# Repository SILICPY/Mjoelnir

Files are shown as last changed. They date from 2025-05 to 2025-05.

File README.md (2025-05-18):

# 🔨 Mjölnir
Eine dekorative Leuchte angelehnt an Marvels Interpretation des Hammers Thors

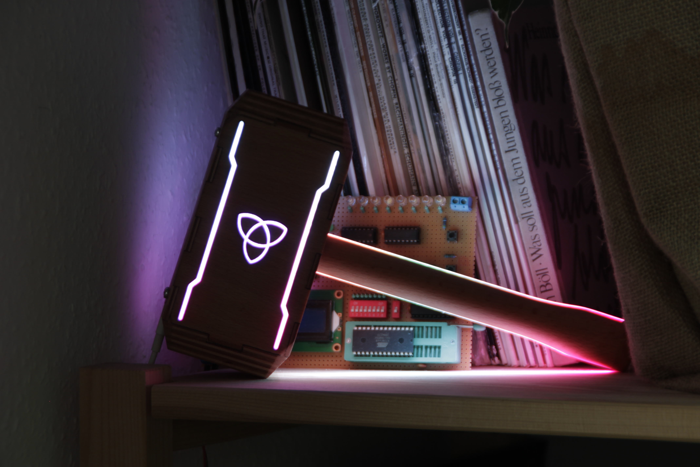
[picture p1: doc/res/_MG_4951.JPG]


## 📖 Dokumentation
<!-- - [Mjölnir dokumentation](doc/) -->
- [WLED Dokumentation](https://kno.wled.ge/) - ESP32 LED Firmware
- [LedFX Dokumentation](https://docs.ledfx.app/en/stable/) - Rhythmuserkennungssoftware
- [Reparaturanleitung (WIP)](/doc/repairguide.md)

## 🚀 Erste Schritte
### 🛠️ Systemkonfiguration
- [x] [ESP32](https://amzn.eu/d/4D6PdJC) mit [WLED Firmware](https://github.com/wled/WLED/releases/latest) [flashen](kno.wled.ge/basics/install-binary/)
- [x] [ATtiny85 / Digispark USB](https://amzn.eu/d/9wXMY9x) mit [USB-C Supervisor Firmware flashen](/software/usb_controller/)
- [x] Verbinden mit AP des ESP32
    - Netzwerkname: `WLED-AP`
    - Passwort: `wled1234`
- [x] Navigiere zu http://4.3.2.1/settings/sec
    - [x] Hochladen der [Preset-Konfigurationsdatei](/config/wled_presets_Mjoelnir.json) unter "Restore presets"
    - [x] Hochladen der [System-Konfigurationsdatei](/config/wled_cfg_Mjoelnir.json) unter "Restore configuration"
### 🛜 WLAN Konfiguration
- [ ] Verbinden mit neuem AP des ESP32
    - Netzwerkname: `Mjoelnir`
    - Passwort: `wled1234`
- [ ] Navigiere zu http://mjoelnir.local/settings/wifi
    - [ ] Scannen nach verfügbaren Netzwerken
    - [ ] Auswählen des eigenen Netzwerkes / WLANs aus Dropdown unter "Network name"
    - [ ] Passwort des gewählten Netzwerkes unter "Network password" eintragen
    - [ ] Bestätigen durch "Save & Connect"
### 💡 Nutzung
- [ ] Während Verbindung mit Heimnetzwerk besteht: Navigiere zu http://mjoelnir.local
- [ ] [YT-Tutorial](https://www.youtube.com/watch?v=YQyN5y-gb6I) zur Verwendung der WLED Benutzeroberfläche

## 🖼️ Bilder
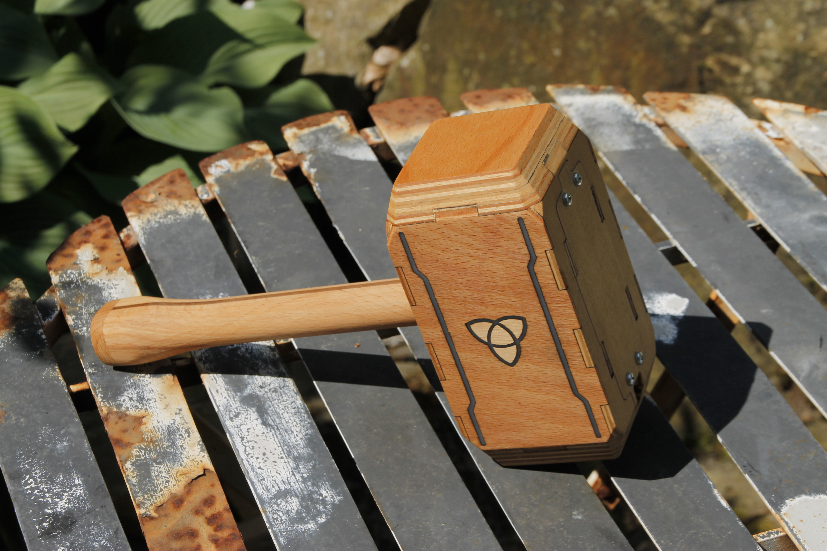
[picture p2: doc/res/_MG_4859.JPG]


## 🔧 Fehlerbehebung
| Problem | Erklärung | Lösungsansatz |
| --- | --- | --- |
| Mittlere **LEDs** leuchten **rot** auf, <br> keine Ansteuerungsmöglichkeit | Falsches **Netzteil** verwendet; <br> Falsches **Kabel** verwendet | Verwende ein Netzteil, welches <br> **mindestens 5V ⎓ 2.4A** zur Verfügung stellt; <br> Verwende ein **USB-C zu USB-C** Kabel |

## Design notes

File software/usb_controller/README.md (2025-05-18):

# USB-C Supervisor Firmware

## 🎯 Verwendungzweck
- Überwacht Kapabilitäten der verwendeten Spannungsquqelle
- Verhindert Zerstörung der Spannungsquelle
- Sorgt für Einhaltung der USB-C-Guidlines

## 🛠️ Kompilation und Upload der Firmware
Zur Kompilation wird das [PlatformIO](https://platformio.org/) Tool verwendet.

Der Upload auf den [ATtiny85 / Digispark USB](https://amzn.eu/d/9wXMY9x) erfolgt über ISP mithilfe eines [Arduino Unos](https://store.arduino.cc/products/arduino-uno-rev3).

### Vorbereitung

Schließe den ATtiny85 / Digispark USB wie folgt an den Arduino Uno an:

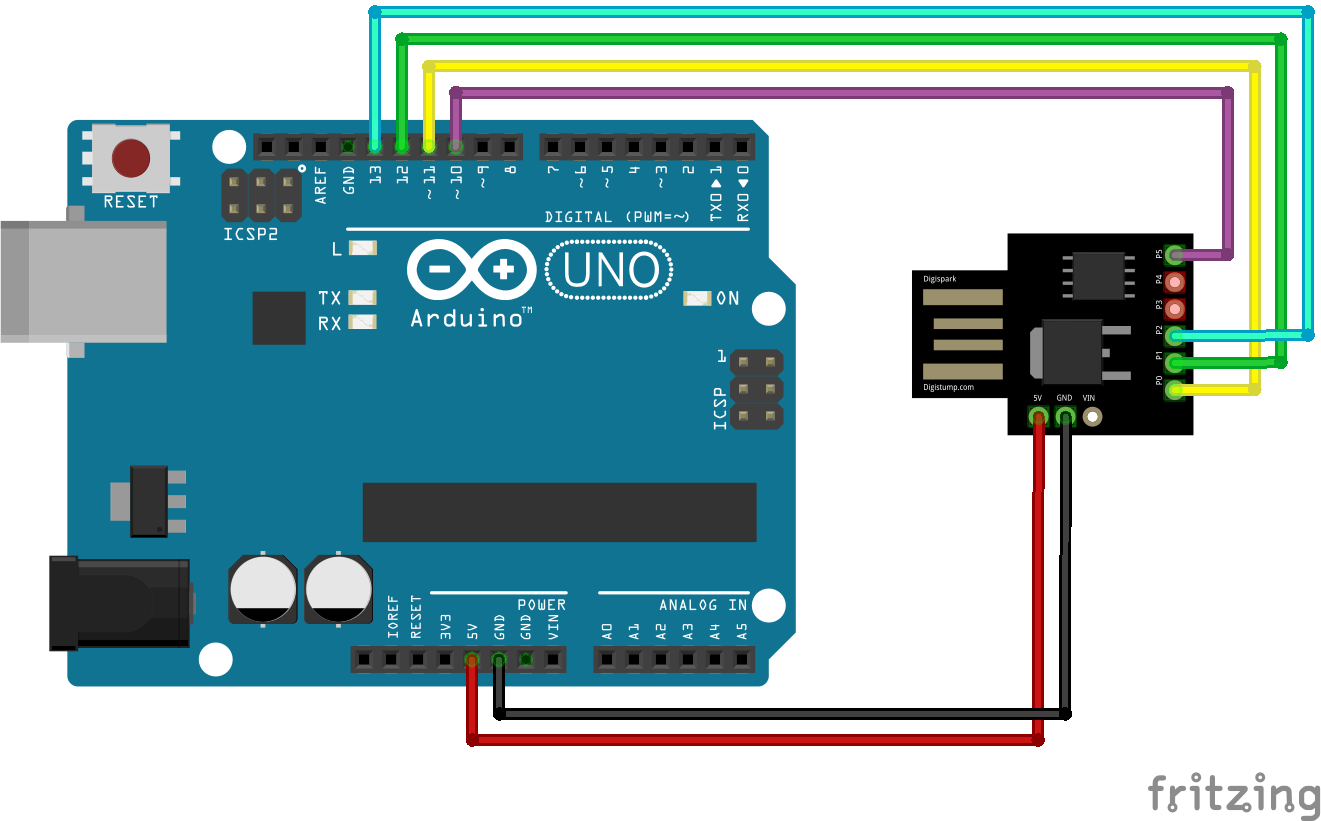
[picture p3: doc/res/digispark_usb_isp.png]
Schaltplan zur Programmierung des Digispark USB


Stelle nach Anschluss des Arduino Unos an deinen Computer sicher, dass der Wert der Option `upload_port` in der [platformio.ini](/software/usb_controller/platformio.ini) Konfigurationsdatei dem [Port des Arduinos](https://www.mathworks.com/help/matlab/supportpkg/find-arduino-port-on-windows-mac-and-linux.html) entspricht.

Flashe anschließend die [ArduinoISP Firmware](https://docs.arduino.cc/built-in-examples/arduino-isp/ArduinoISP/) auf den Arduino Uno.

### Visual Studio Code
Stelle sicher, dass die [PlatformIO Extension für VSCode](https://marketplace.visualstudio.com/items?itemName=platformio.platformio-ide) installiert ist.

Öffne den Ordner [software/usb_controller/](/software/usb_controller/) des Repos in VSCode.

Starte den Kompilations- und Uploadprozess über die Tastenkombination `CTRL+ALT+U`

### PlatformIO-Core
Navigiere im Terminal in den Ordner [software/usb_controller/](/software/usb_controller/) des Repos
```console
cd software/usb_controller
```
Starte den Kompilations- und Uploadprozess mit
```console
platformio run -t upload
```

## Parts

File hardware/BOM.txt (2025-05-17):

Elektronik pro Lampe:

<Beschreibung>: <Mengenangabe>
<Produktbeispiel>

ESP32 D1 Mini Dev Board: 1 Stück
https://amzn.eu/d/4D6PdJC

WS2812b LED Strip (144 LEDs / m): 1 m
https://amzn.eu/d/igvtXYB

ATtiny85 / Digispark USB: 1 Stück
https://amzn.eu/d/9wXMY9x

USB C Breakout Board: 1 Stück
https://amzn.eu/d/f5a8ZON

3 Pin JST Steckverbinder 22 AWG (5A): 3 Paar
https://amzn.eu/d/1D8DPcv

Holz pro Lampe:

<Beschreibung>: <Mengenangabe>

4 mm Multiplex / Furnier: ~ 0.12 m²
4 mm Quadratleiste: ~ 60 cm
22 mm Rundholzstab: 18 cm
30 mm Rundholzstab: ~ 3 cm
3 mm Acrylglas: ~ 0.02 m²
Beliebiges Holz für optionales Podest

Sonstiges:

Epoxidharz für Feinarbeiten
Farbpigment zum Einfärben von Epoxidharz (weiß milchig)
Epoxidharzkleber (UHU Plus Schnellfest)
Kabel (min. Stromfestigkeit: ca. 2-3 A)
USB-C auf USB-C Kabel
USB-C Netzteil (min. 2A @ 5V)

M3 Gewindeschraube 16 mm: 4 Stück
https://www.bauhaus.info/gewindeschrauben/profi-depot-gewindeschraube-vz/p/10807519

M3 Gewindeschraube 10 mm (oder gekürzte M3 Gewindeschraube 16 mm): 2 Stück
https://www.bauhaus.info/gewindeschrauben/stabilit-zylinderschraube-a2/p/10790640

M3 Sechskantmutter: 6 Stück
https://www.bauhaus.info/sechskantmuttern/profi-depot-sechskantmutter-vz/p/10825618

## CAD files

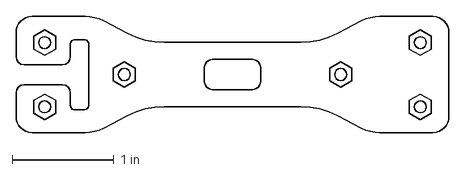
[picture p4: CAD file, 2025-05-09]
hardware/cad/drawings/in/verschluss_gegenstueck.dxf
4.25 x 1.14 in

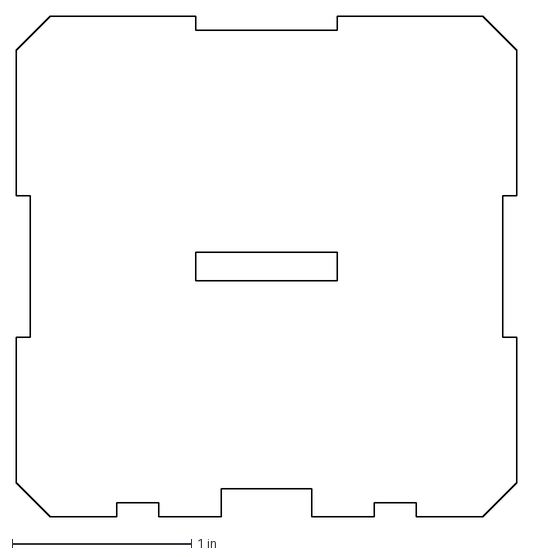
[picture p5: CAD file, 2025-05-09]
hardware/cad/drawings/in/kappe_rechts_2.dxf
2.80 x 2.80 in

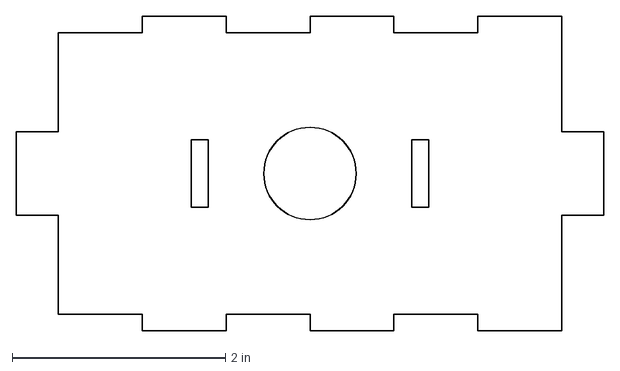
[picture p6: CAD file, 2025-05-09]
hardware/cad/drawings/in/wand_oben.dxf
5.51 x 2.95 in

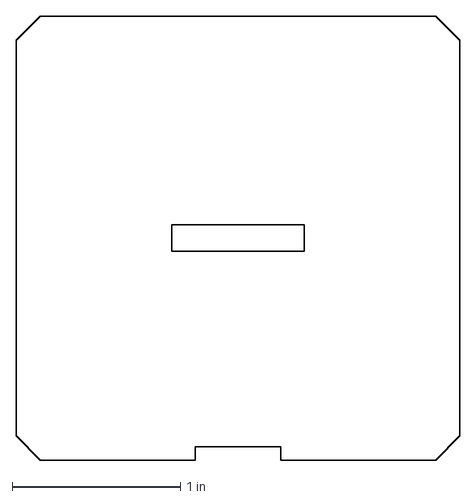
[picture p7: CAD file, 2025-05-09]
hardware/cad/drawings/in/kappe_rechts_3.dxf
2.64 x 2.64 in

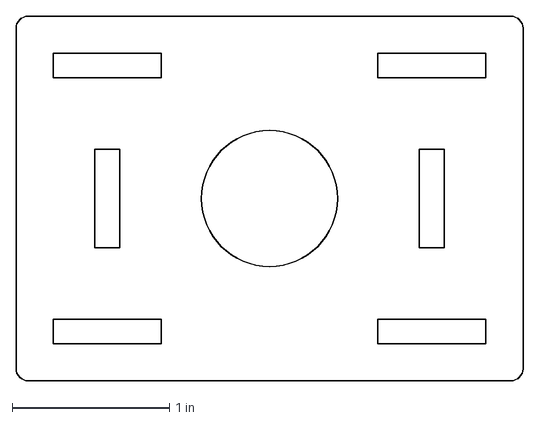
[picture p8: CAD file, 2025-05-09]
hardware/cad/drawings/in/griff_halterung.dxf
3.23 x 2.32 in

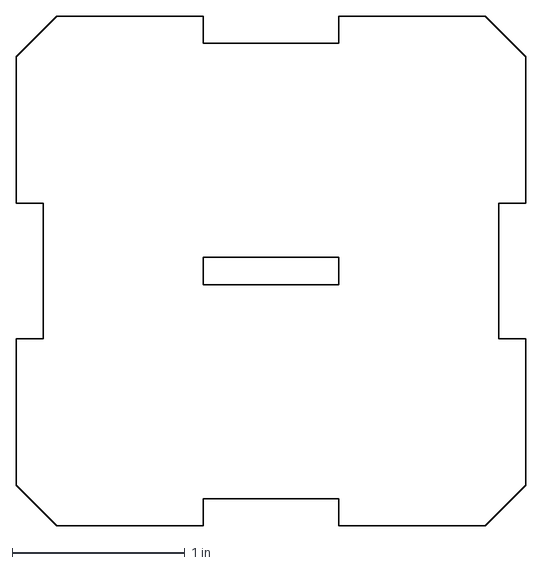
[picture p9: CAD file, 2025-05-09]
hardware/cad/drawings/in/kappe_links_1.dxf
2.95 x 2.95 in

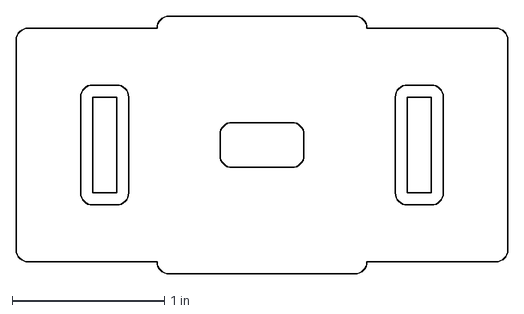
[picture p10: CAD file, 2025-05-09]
hardware/cad/drawings/in/griff_sperre.dxf
3.23 x 1.69 in

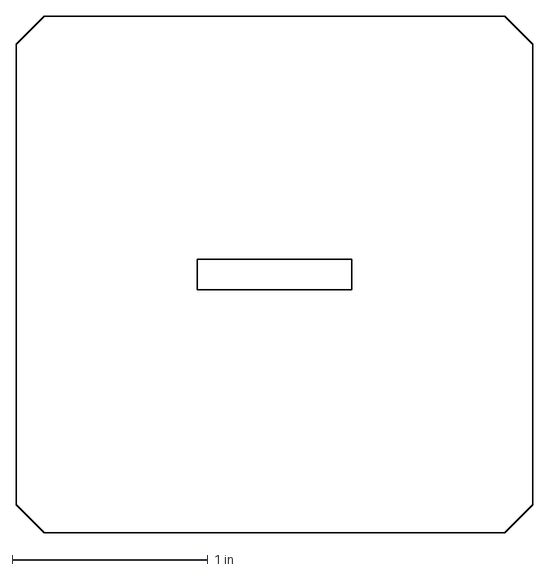
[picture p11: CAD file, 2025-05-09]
hardware/cad/drawings/in/kappe_links_3.dxf
2.64 x 2.64 in

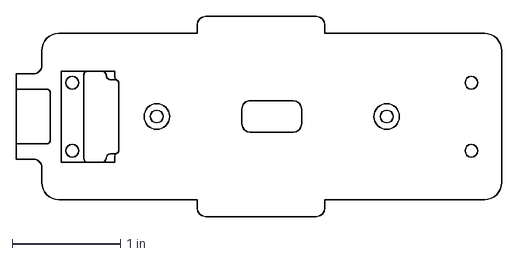
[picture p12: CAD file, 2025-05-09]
hardware/cad/drawings/in/sperre.dxf
4.49 x 1.85 in

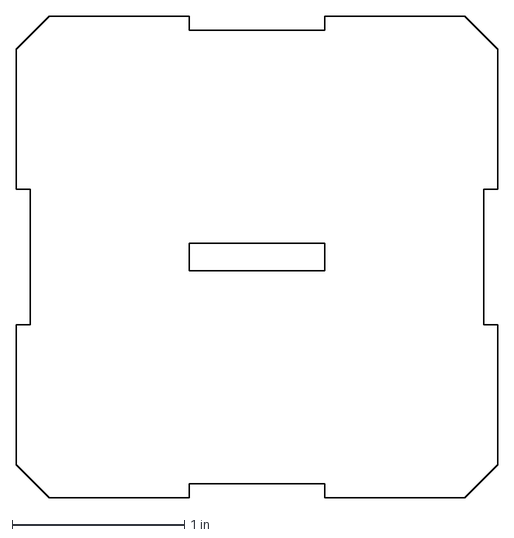
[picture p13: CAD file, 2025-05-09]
hardware/cad/drawings/in/kappe_links_2.dxf
2.80 x 2.80 in

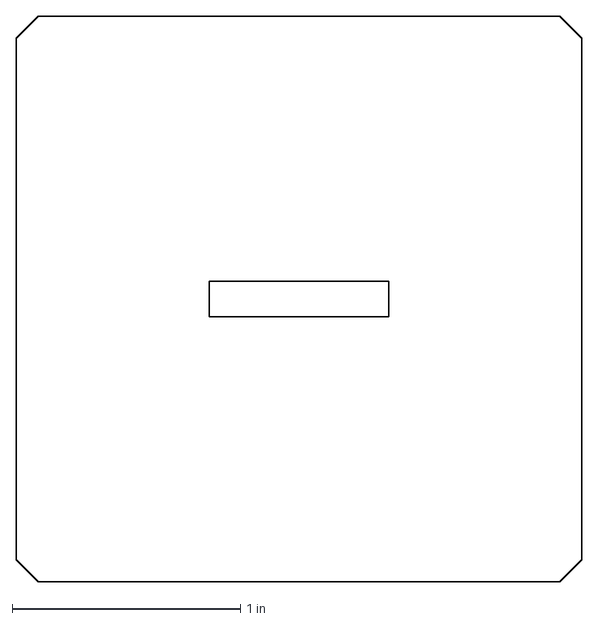
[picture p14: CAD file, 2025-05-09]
hardware/cad/drawings/in/kappe_rechts_4.dxf
2.48 x 2.48 in

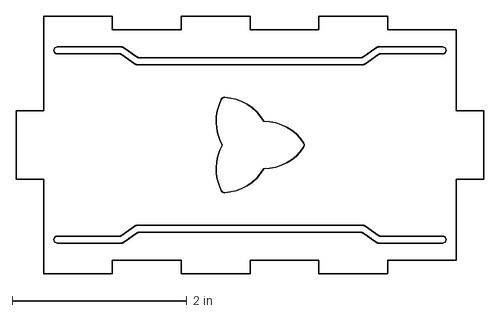
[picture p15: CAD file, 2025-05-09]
hardware/cad/drawings/in/wand_hinten.dxf
5.35 x 2.95 in

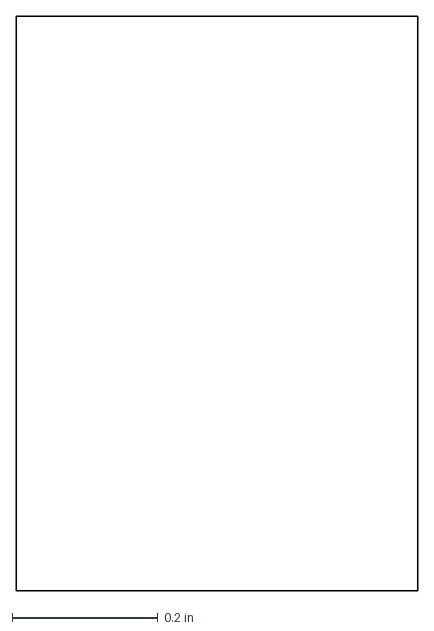
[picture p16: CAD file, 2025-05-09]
hardware/cad/drawings/in/klebehilfe_rechts.dxf
0.551 x 0.787 in

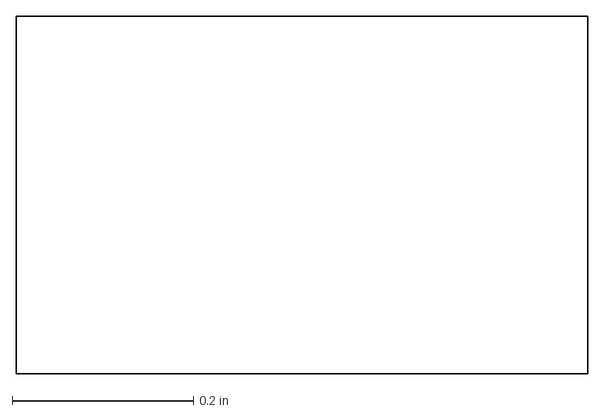
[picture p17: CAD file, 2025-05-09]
hardware/cad/drawings/in/halterungssteg_1.dxf
0.63 x 0.394 in

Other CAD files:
hardware/cad/drawings/in/verschluss.dxf
hardware/cad/drawings/in/kappe_rechts_1.dxf
hardware/cad/drawings/in/led_befestigung_hinten.dxf
hardware/cad/drawings/in/led_befestigung_vorne.dxf
hardware/cad/drawings/in/wand_unten.dxf
hardware/cad/drawings/in/wand_vorne.dxf

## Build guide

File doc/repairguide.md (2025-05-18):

# Reparatur

## Demontage des Hammerkopfes

### 1. Öffnen der Abdeckung
- Schrauben der Abdeckung lösen

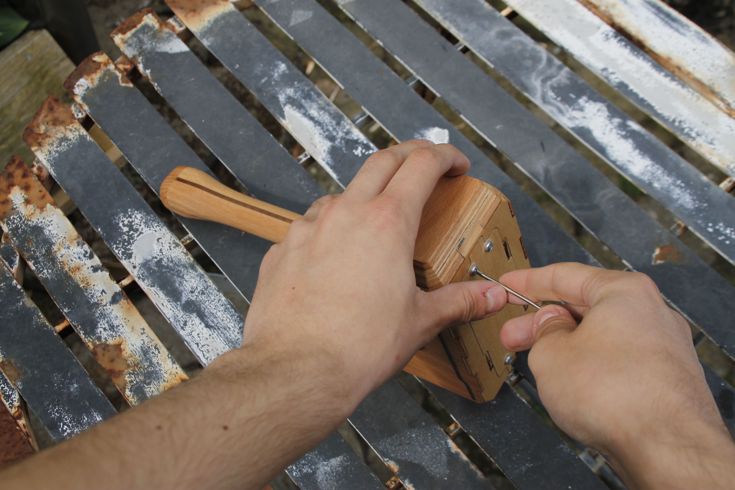
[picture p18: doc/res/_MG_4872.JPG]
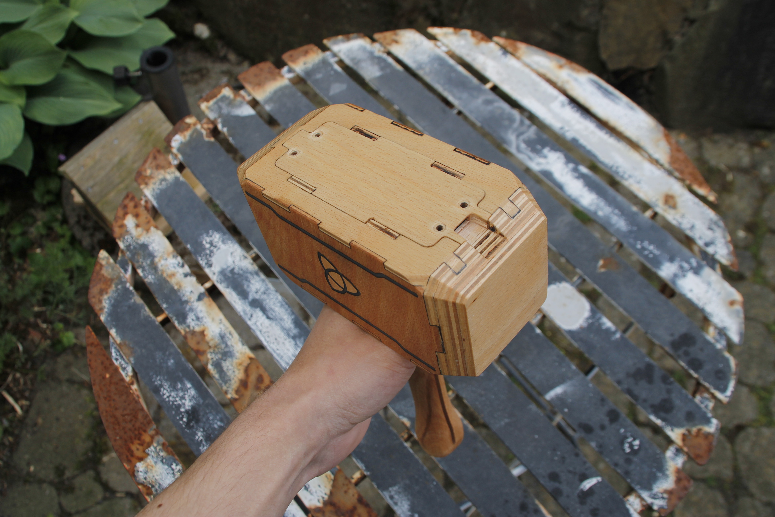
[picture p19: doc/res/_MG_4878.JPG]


- Eingestecktes USB Kabel vorsichtig nach oben ziehen und Abdeckung lösen

https://github.com/user-attachments/assets/87b6fe2a-6ad5-4222-91ca-994627045406

### 2. Öffnen des Verschlusses

- Nach Entfernen des USB Kabels, Verschluss nach hinten schieben, dort herunterdrücken und herausnehmen

https://github.com/user-attachments/assets/4af9b3b4-d7bc-4e28-bcf6-118e3d1298a7

### 3. Lösen der Platine

- Steckverbinder zwischen Platine und Hammerkopf lösen und Platine sowie Verschluss herausnehmen

### 4. Lösen der Steckverbindungen

- Steckverbinder zwischen LED Boards lösen

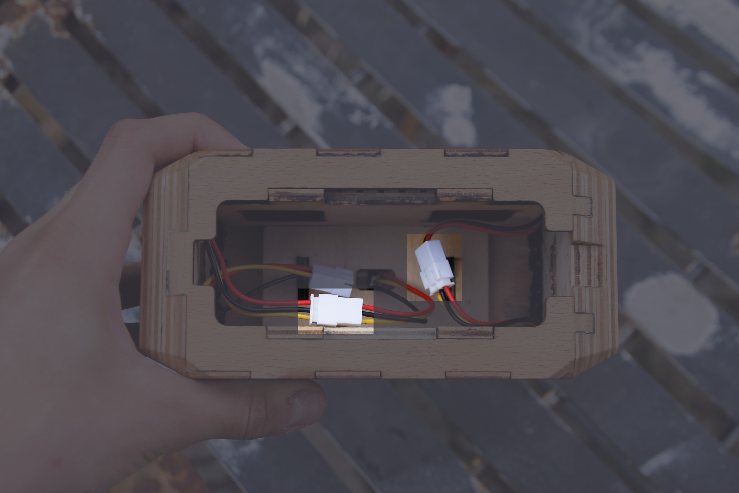
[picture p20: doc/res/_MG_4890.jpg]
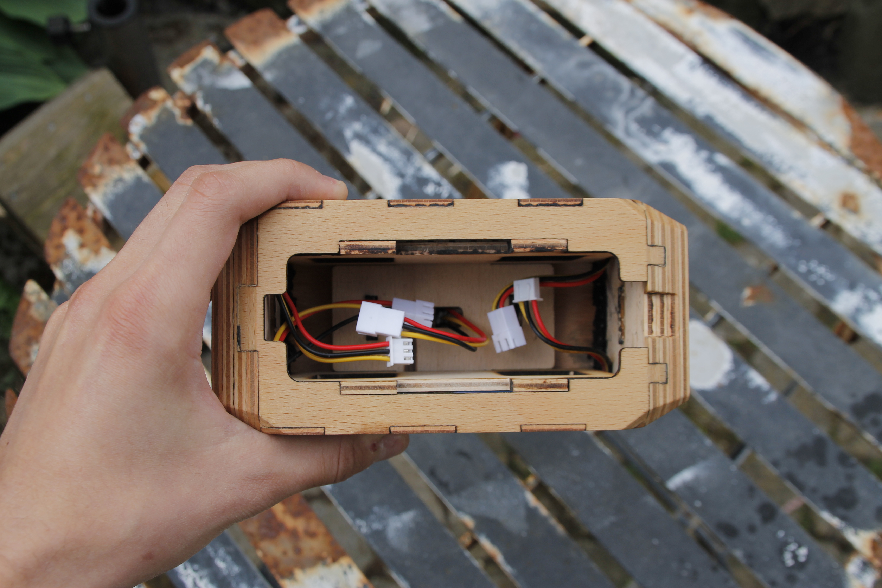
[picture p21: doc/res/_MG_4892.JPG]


### 5. LED Boards entfernen

- LED Boards nacheinander aus Verankerung ziehen, geneigt Richtung Mitte bewegen und herausnehmen

https://github.com/user-attachments/assets/ced3f516-bf56-49fe-b68f-585f7b4db71a

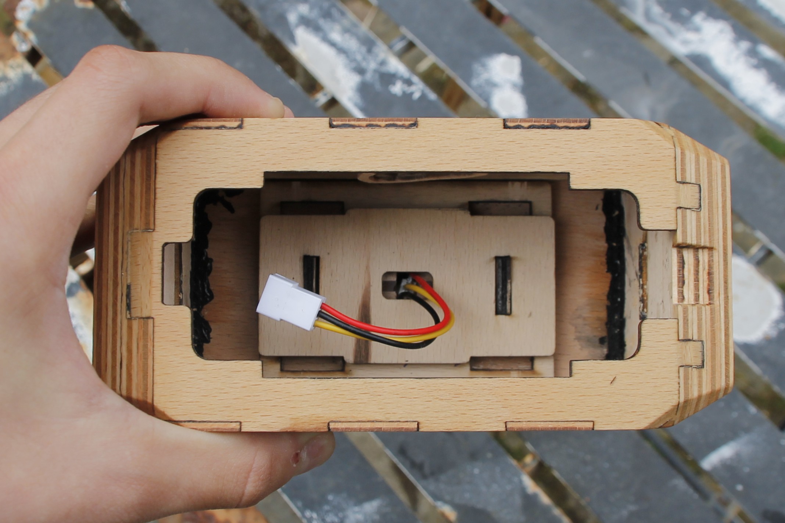
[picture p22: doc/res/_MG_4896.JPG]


### 6. LEDs aus Griff entfernen

- Die LEDs sowie die Sperre durch Ziehen am Steckverbinder lösen und herausnehmen

- LEDs aus Sperre lösen

https://github.com/user-attachments/assets/b0a4f914-e4c2-444a-b6bf-969ce0bceb53

### 🪛 7. Demontage abgeschlossen!



## Zusammenbau des Hammerkopfes

### 1. Positionierung der LEDs im Griff

-  Die LEDs durch Sperre führen, um 90° drehen und im Griff positionieren

https://github.com/user-attachments/assets/28b4ab3f-4345-4afb-bd30-a3cdea6a031f

### 2. Montage der LED Boards im Hammerkopf

- Die LED Boards nacheinander so in Hammerkopf einsetzen, dass die drei mittigen LEDs in Richtung des Ornamentes zeigen

- **_Falls sich das LED Board nicht einsetzen lässt, versuche, wie im zweiten Teil des Videos gezeigt, das LED Board nach innen zu ziehen_**

https://github.com/user-attachments/assets/b8407089-f7b8-45ab-b9c5-5b3aa16eaa49

### 3. Zusammenstecken der Steckverbindungen

- Die oberste Buchse an einem der LED Boards zur Seite biegen

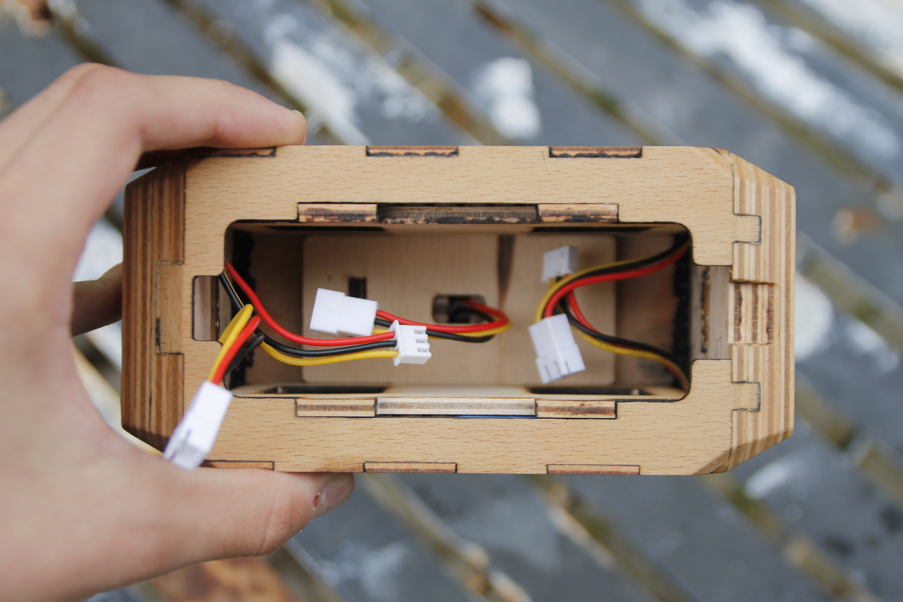
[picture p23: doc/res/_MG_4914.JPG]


- Verbinden der beiden unteren Steckverbinder der LED Boards

- Verbinden der Buchse der LEDs im Griff mit dem noch freien Steckverbinder des LED Boards

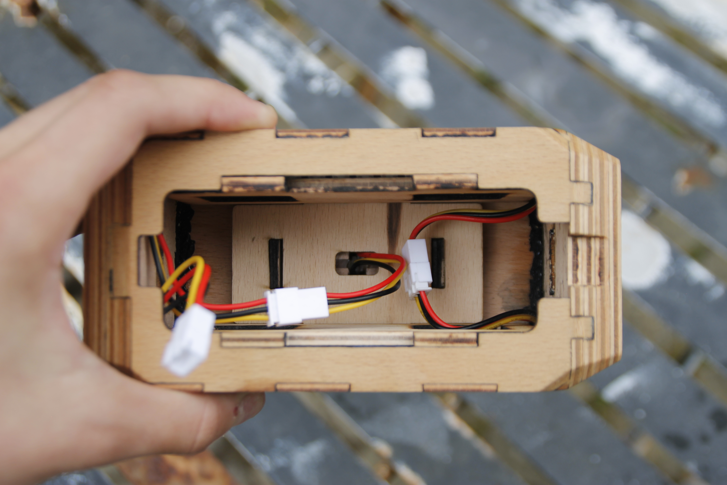
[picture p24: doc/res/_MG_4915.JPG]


### 4. Verbinden Platine mit Steckverbinder

- Verbinden des Steckverbinders an der Platine mit der abgesonderten Buchse im Hammerkopf

### 5. Einbau der Platine sowie Verschluss

- Platine in Hammerkopf schieben

- Verschluss gegenüber der USB Aussparung einsetzen, herunterdrücken und in Richtung der USB Aussparung schieben

- USB-C Breakout Platine in Aussparung des Verschlusses einsetzen

https://github.com/user-attachments/assets/40e28e35-0eea-4673-af5a-971eeecef7a7

### 6. Montage der Abdeckung

- Abdeckung positionieren und herunterdrücken

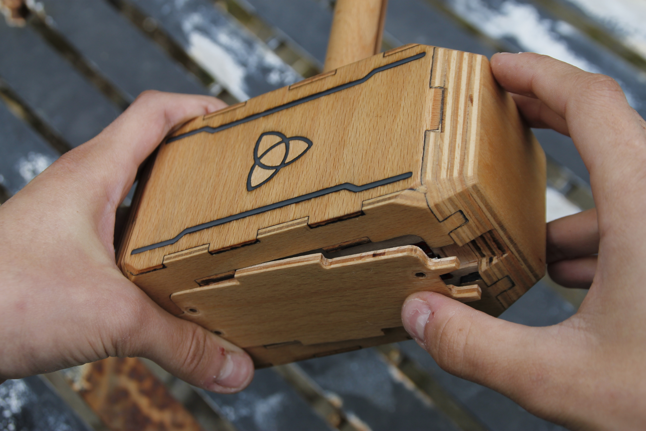
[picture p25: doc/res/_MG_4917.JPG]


- Abdeckung mit Verschluss verschrauben

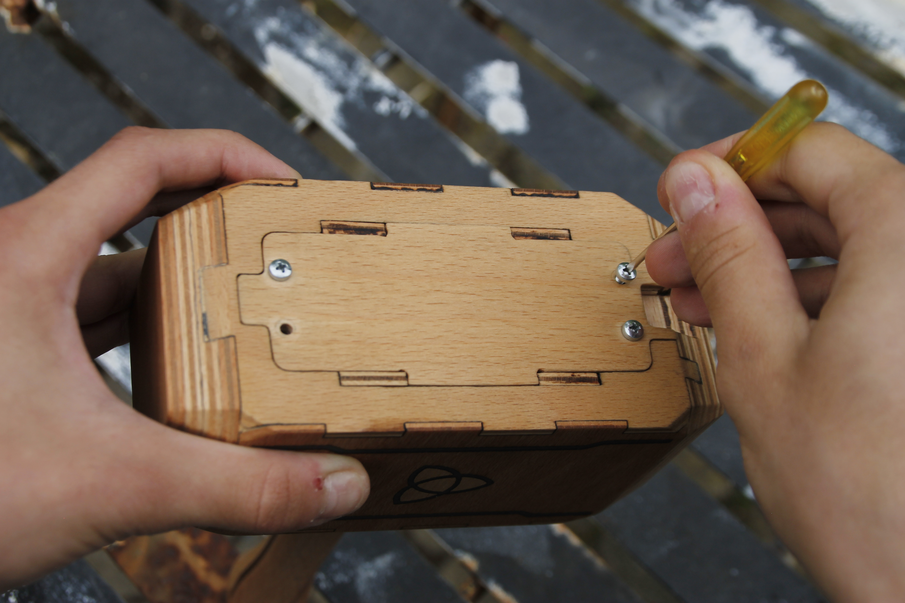
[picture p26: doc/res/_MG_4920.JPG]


### 🚀 7. Montage abgeschlossen!

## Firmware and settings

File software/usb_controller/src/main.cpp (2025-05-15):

#include <Arduino.h>

#include <Adafruit_NeoPixel.h>

#define CC_VOLTAGE_THRESH_3A 1.31
#define CC_ADC_THRESH_3A (int) ((CC_VOLTAGE_THRESH_3A / 5) * 1024)

#define CC1_PIN A1
#define CC2_PIN A2
#define RST_PIN PB0

#define PIN_MASK ((1 << RST_PIN) | (1 << LED_BUILTIN))

#define PIXEL_PIN PB3
#define PIXEL_COUNT 70
#define US_SLIP (PIXEL_COUNT * 30)

#define SWITCH_DELAY 50

class Timer {
  unsigned long currentTime;
  unsigned long duration;

public:
  void start(unsigned long duration) {
    this->duration = duration;
    this->currentTime = millis();
  }

  bool isExpired() {
    return (millis() - currentTime >= duration);
  }
};

enum State {
  DISABLED,
  SWITCHING,
  ENABLED,
};

Adafruit_NeoPixel pixels = Adafruit_NeoPixel(PIXEL_COUNT, PIXEL_PIN, NEO_GRB + NEO_KHZ800);

State currentState;
Timer timer;

void doErrAnim() {
  for (size_t i = 0; i < 3; ++i) {
    pixels.setPixelColor(16 + i, pixels.Color(50 * abs(sin((millis() / 4000.0) * 2.0 * PI)), 0, 0));
    pixels.setPixelColor(51 + i, pixels.Color(50 * abs(sin((millis() / 4000.0) * 2.0 * PI)), 0, 0));
  }
  pixels.show();
}

void updateStatus() {
  PORTB = (PORTB & (0xff ^ PIN_MASK)) | (currentState == State::ENABLED ? 1 << RST_PIN : 1 << LED_BUILTIN);

  if (currentState == State::DISABLED) {
    pinMode(PIXEL_PIN, OUTPUT);
    doErrAnim();
  } else {
    pinMode(PIXEL_PIN, INPUT);
  }
}

void setup() {
  DDRB = PIN_MASK;

  currentState = State::SWITCHING;
  timer.start(SWITCH_DELAY);

  pixels.begin();
}

void loop() {
  if (max(analogRead(CC1_PIN), analogRead(CC2_PIN)) > CC_ADC_THRESH_3A) {
    if (currentState == State::DISABLED) {
      currentState = State::SWITCHING;
      timer.start(SWITCH_DELAY);
    } else if (currentState == State::SWITCHING && timer.isExpired()) {
      currentState = State::ENABLED;
    }
  } else {
    if (currentState == State::ENABLED) {
      currentState = State::SWITCHING;
      timer.start(SWITCH_DELAY);
    } else if (currentState == State::SWITCHING && timer.isExpired()) {
      currentState = State::DISABLED;
    }
  }

  updateStatus();
}

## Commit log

2025-05-09 feat(cad): add drawings of machined parts
    [griff_halterung.dxf, griff_sperre.dxf, halterungssteg_1.dxf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]
2025-05-15 feat(usb): add switch on/off delay
2025-05-15 feat(hard): add fritzing circuit diagram
    [circuit_diagram.fzz]
2025-05-15 feat(hard): add BOM
2025-05-15 chore: refactor file structure
    [circuit_diagram.fzz, griff_halterung.dxf, griff_sperre.dxf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]
2025-05-15 fix(hard): correct BOM item quantity
2025-05-15 feat(soft): add default config files for wled/ledfx
2025-05-15 chore: improve folder name scheme
    [circuit_diagram.fzz, griff_halterung.dxf, griff_sperre.dxf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]
2025-05-15 fix(soft): fix LedFX virtuals/segment boundaries
2025-05-15 feat(soft): add default WLED ledmap.json
2025-05-16 fix(config): set WLED brightness limiter to 2000 mA
2025-05-17 docs: add schematic for ATTiny85 ISP programming
    [digispark_usb_isp.fzz]
2025-05-17 feat(config): add 'Dreamy Complementary' LedFX scene
2025-05-18 docs: move resources into res/ directory
    [digispark_usb_isp.fzz]
2025-05-18 docs: add assembly instructions to repairguide
2025-05-18 docs: add image with LEDs enabled to root README
